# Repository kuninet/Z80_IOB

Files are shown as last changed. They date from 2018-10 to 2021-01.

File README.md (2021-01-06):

View this project on [CADLAB.io](https://cadlab.io/project/23712). 

# Z80 I/Oボード (KZ80-IOB)

詳細は[以下のwiki](https://github.com/kuninet/Z80_IOB/wiki)にまとめます。
ご覧ください。

https://github.com/kuninet/Z80_IOB/wiki

## 概要

- SBC8080ルーズキットバスにつながるI/Oボードです。
  - [Z80 CPUボード(KZ80-CPUB)](https://github.com/kuninet/Z80_CPUB/wiki)、[SBC8080](https://vintagechips.wordpress.com/2018/06/24/sbc8080-cpu%E3%83%AB%E3%83%BC%E3%82%BA%E3%82%AD%E3%83%83%E3%83%88/)、[SBC8085](https://vintagechips.wordpress.com/2018/08/27/sbc8085%e3%81%8c%e5%ae%8c%e6%88%90/)と組み合わせた稼働を確認しています。
  - 8255パラレルI/O LSIを搭載しています。(Lチカに最適)
  - 8251シリアルチップを搭載しています。
  - 将来 ArduinoコネクタのFM音源シールドを搭載するためのコネクタを装備しています。(これ以外の使いみちはありませんが...)

## 回路図

[回路図はこちら](image/Z80-8251-PPI.pdf)です。

## 部品表

[部品表はこちら](KiCAD/Z80-8251-PPI.ods)です。

※LibreOffice/OpenOfficeのcalcで開ける形式となっています。

## ライセンス

- 本リポジトリのデータは MIT License のもとで公開します。[LICENSE.txt](LICENSE.txt)を参照して下さい。

## その他注意点等

- 8251シリアルLSIのアドレスデコードをSBC8080 SUBボードと合わせる場合は、アドレスデコードジャンパ(J2)の1-2を短絡(I/Oアドレス:00h)してください。
- 8255パラレルI/O LSIのアドレスデコードジャンパ(J3)は 13-14を短絡(I/Oアドレス:C0h)が推奨です。

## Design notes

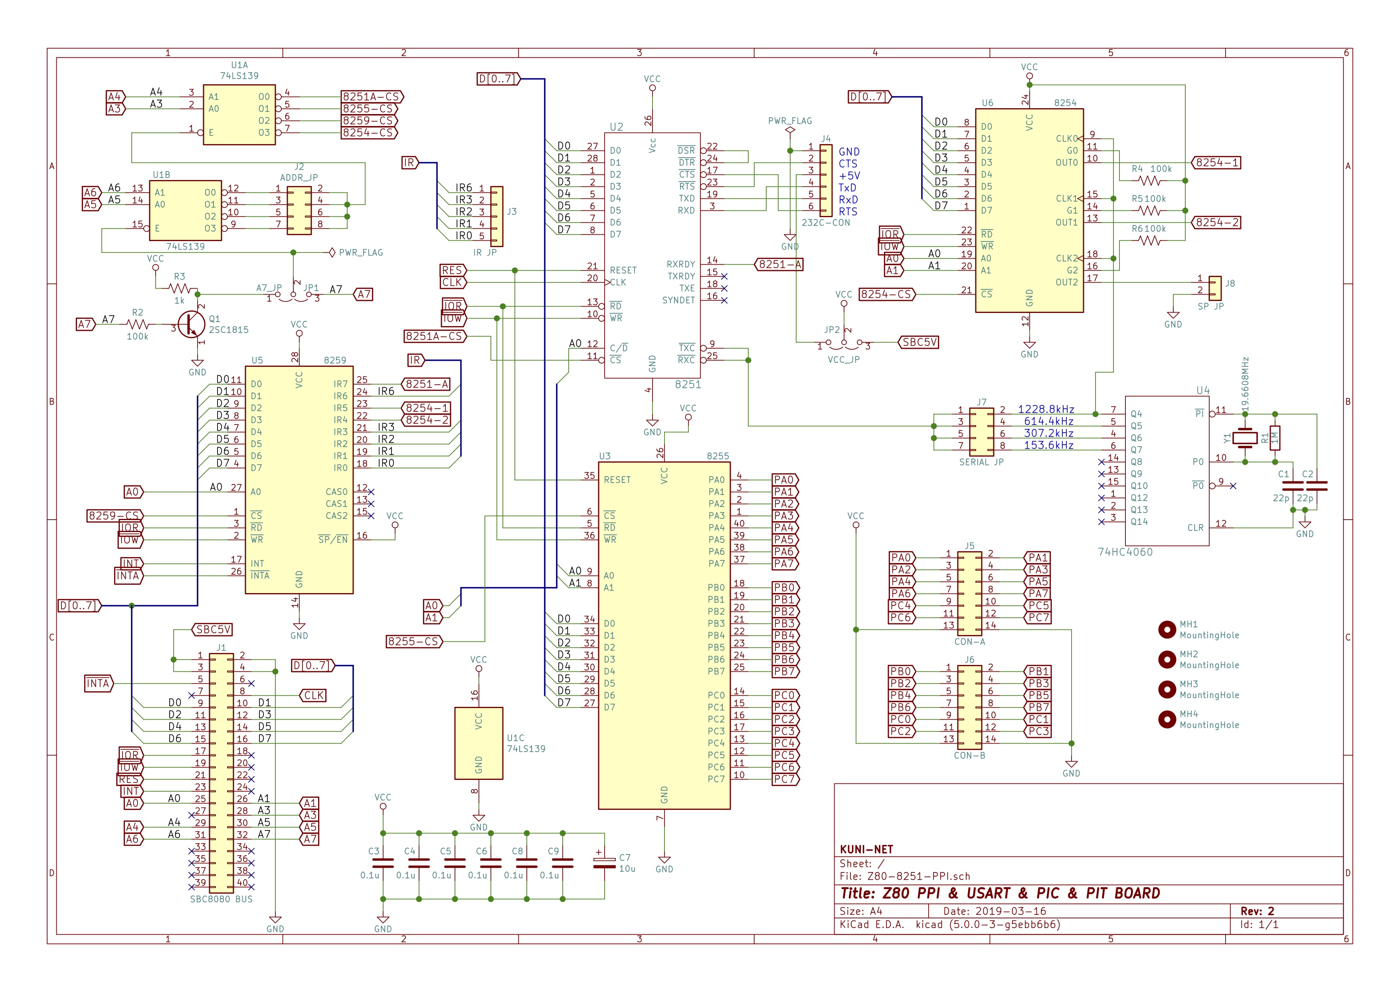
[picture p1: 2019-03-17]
image/Z80-8251-PPI.jpg

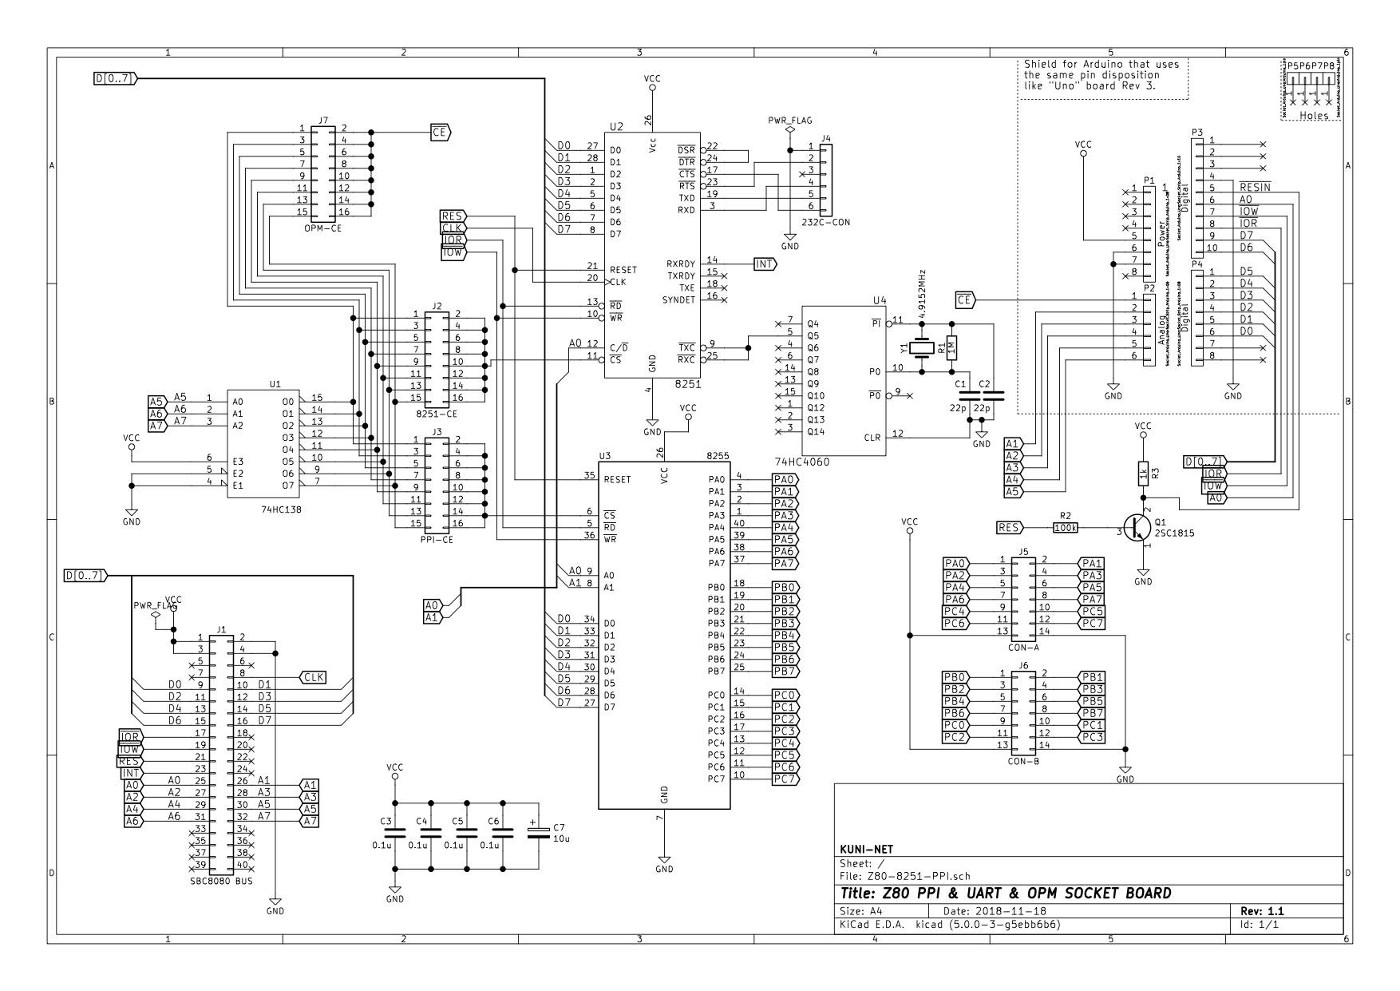
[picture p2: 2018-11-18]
image/Z80-8251-PPI-REV1.jpg

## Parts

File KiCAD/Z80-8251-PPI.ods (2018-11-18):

部品番号 | 仕様 | 数量 | 代替可能品 | 備考 | Footprint
P1 | ピンソケット 1列x8pin | 1 | - | ピンヘッダ1列x40pin等を切り分け | Socket_Arduino_Uno:Socket_Strip_Arduino_1x08
P2 | ピンソケット 1列x6pin | 1 | - | ピンヘッダ1列x40pin等を切り分け | Socket_Arduino_Uno:Socket_Strip_Arduino_1x06
P4 | ピンソケット 1列x8pin | 1 | - | ピンヘッダ1列x40pin等を切り分け | Socket_Arduino_Uno:Socket_Strip_Arduino_1x08
P3 | ピンソケット1列x10pin | 1 | - | ピンヘッダ1列x40pin等を切り分け | Socket_Arduino_Uno:Socket_Strip_Arduino_1x10
U1 | 74HC138 | 1 | 74HCT138 |  | Housings_DIP:DIP-16_W7.62mm_Socket
U2 | UPD8251AFC | 1 | Intel 8251 |  | Housings_DIP:DIP-28_W15.24mm_Socket
U3 | UPD8255AC-5 | 1 | M5L8255AP-5 |  | Housings_DIP:DIP-40_W15.24mm
U4 | 74HC4060 | 1 | 74HCT4060 |  | Housings_DIP:DIP-16_W7.62mm_Socket
J1 | 40 ピン L 型ボックスヘッダ | 1 | L型2列ピンヘッダ | L型2列ピンヘッダでも可 | Pin_Headers:Pin_Header_Angled_2x20
J2、J3、J7 | ピンヘッダ 2列x8pin | 3 | - | ピンヘッダ2列x40pin等を切り分け | Pin_Headers:Pin_Header_Straight_2x08
J4 | L型1列ピンヘッダ 6pin | 1 | - | L型ピンヘッダ1列x40pin等を切り分け | Pin_Headers:Pin_Header_Angled_1x06
J5、J6 | 14pin ボックスヘッダ | 2 | ピンヘッダ 2列x7pin | ピンヘッダで代替も可 | Pin_Headers:Pin_Header_Straight_2x07_Pitch2.54mm
Y1 | 4.9152MHz | 1 | 水晶振動子 |  | Crystals:HC-49V
R1 | 1MΩ | 1 | カーボン抵抗器 |  | Resistors_THT:R_Axial_DIN0207_L6.3mm_D2.5mm_P10.16mm_Horizontal
R2 | 100kΩ | 1 | カーボン抵抗器 |  | Resistors_THT:R_Axial_DIN0207_L6.3mm_D2.5mm_P10.16mm_Horizontal
R3 | 1kΩ | 1 | カーボン抵抗器 |  | Resistors_THT:R_Axial_DIN0207_L6.3mm_D2.5mm_P10.16mm_Horizontal
C1、C2 | 22pF | 2 | 積層セラミックコンデンサ |  | Capacitors_THT:C_Rect_L4.0mm_W2.5mm_P2.50mm
C3、C4、C5、C6 | 0.1μF | 4 | 積層セラミックコンデンサ |  | Capacitors_THT:C_Rect_L4.0mm_W2.5mm_P2.50mm
Q1 | 2SC1815 | 1 | 小電力トランジスタ | 1815同等品ならOK
C7 | 10μF | 1 | 電解/タンタルコンデンサ |  | Capacitor_THT:CP_Radial_D5.0mm_P2.50mm

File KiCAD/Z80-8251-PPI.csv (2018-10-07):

Reference | Value | Footprint | Datasheet
P1 | Power | Socket_Arduino_Uno:Socket_Strip_Arduino_1x08
P2 | Analog | Socket_Arduino_Uno:Socket_Strip_Arduino_1x06
P5 | CONN_01X01 | Socket_Arduino_Uno:Arduino_1pin
P6 | CONN_01X01 | Socket_Arduino_Uno:Arduino_1pin
P7 | CONN_01X01 | Socket_Arduino_Uno:Arduino_1pin
P8 | CONN_01X01 | Socket_Arduino_Uno:Arduino_1pin
P4 | Digital | Socket_Arduino_Uno:Socket_Strip_Arduino_1x08
P3 | Digital | Socket_Arduino_Uno:Socket_Strip_Arduino_1x10
U3 | 8255 | Housings_DIP:DIP-40_W15.24mm
U2 | 8251 | Housings_DIP:DIP-28_W15.24mm_Socket
J2 | 8251-CE | Pin_Headers:Pin_Header_Straight_2x08
J3 | PPI-CE | Pin_Headers:Pin_Header_Straight_2x08
U1 | 74HC138 | Housings_DIP:DIP-16_W7.62mm_Socket
J1 | SBC8080 BUS | Pin_Headers:Pin_Header_Angled_2x20
J5 | CON-A | Pin_Headers:Pin_Header_Straight_2x07_Pitch2.54mm
J6 | CON-B | Pin_Headers:Pin_Header_Straight_2x07_Pitch2.54mm
J4 | 232C-CON | Pin_Headers:Pin_Header_Angled_1x06
J7 | OPM-CE | Pin_Headers:Pin_Header_Straight_2x08
U4 | 74HC4060 | Housings_DIP:DIP-16_W7.62mm_Socket
Y1 | 4.9152MHz | Crystals:HC-49V
R1 | 1M | Resistors_THT:R_Axial_DIN0207_L6.3mm_D2.5mm_P10.16mm_Horizontal
C2 | 22p | Capacitors_THT:C_Rect_L4.0mm_W2.5mm_P2.50mm
C1 | 22p | Capacitors_THT:C_Rect_L4.0mm_W2.5mm_P2.50mm
C3 | 0.1u | Capacitors_THT:C_Rect_L4.0mm_W2.5mm_P2.50mm
C4 | 0.1u | Capacitors_THT:C_Rect_L4.0mm_W2.5mm_P2.50mm
C5 | 0.1u | Capacitors_THT:C_Rect_L4.0mm_W2.5mm_P2.50mm
C6 | 0.1u | Capacitors_THT:C_Rect_L4.0mm_W2.5mm_P2.50mm

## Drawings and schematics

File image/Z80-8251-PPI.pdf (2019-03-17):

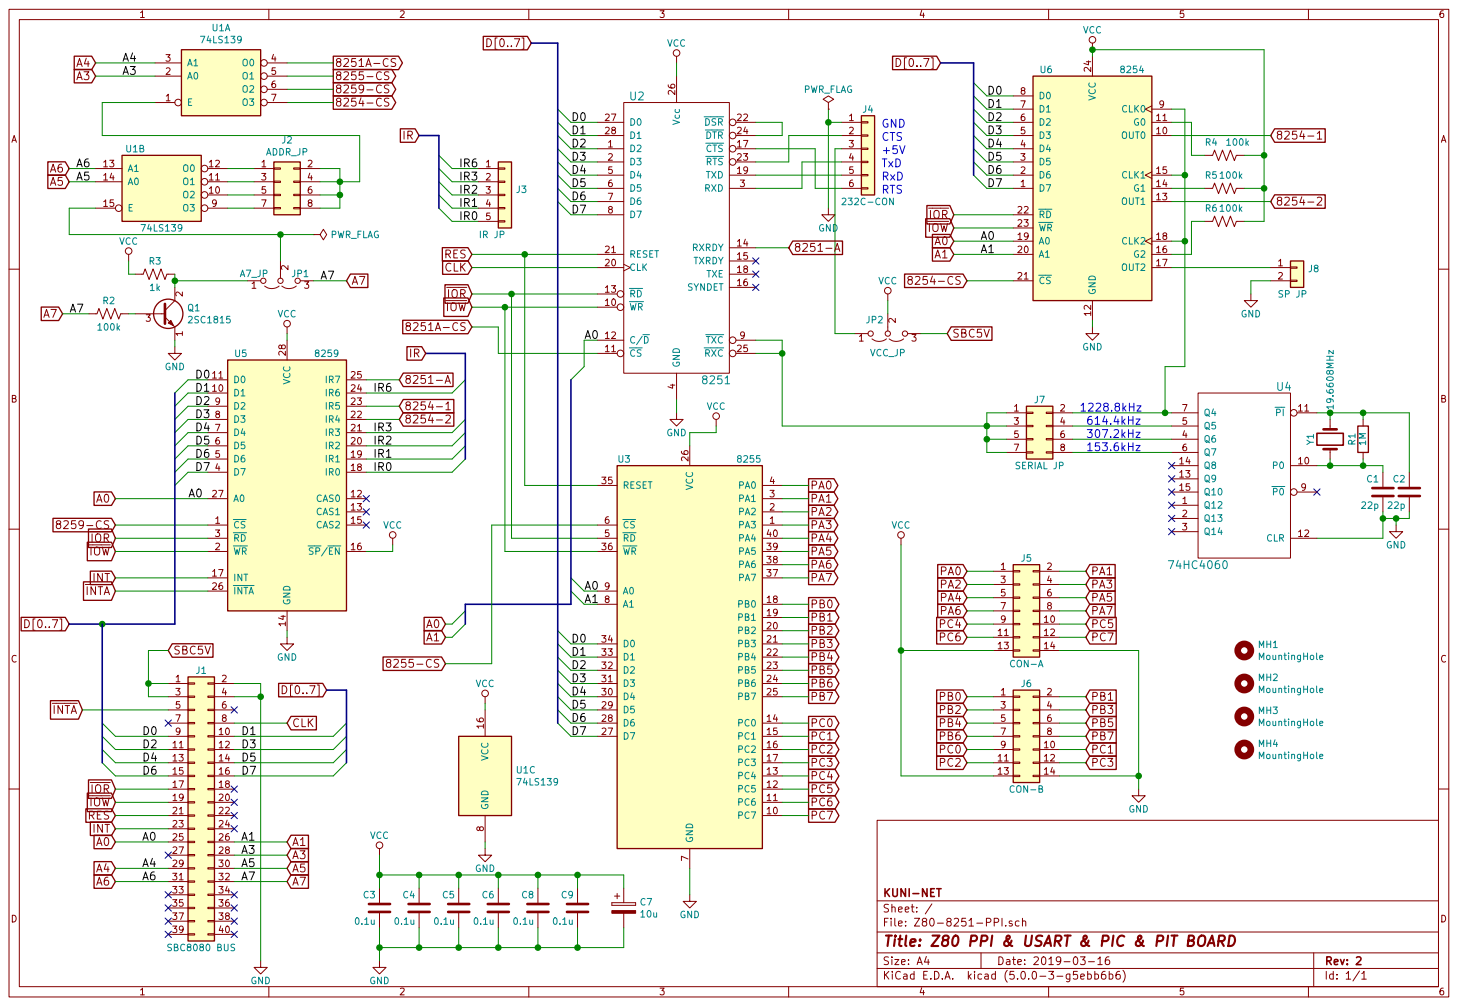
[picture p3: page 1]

7 A1 8 A0 9 U3 8255 D2 1 WR 10 CS 11 C/D 12 RD 13 RXRDY 14 TXRDY 15 SYNDET 16 CTS 17 TXE 18 TXD 19 D3 2 CLK 20 RESET 21 DSR 22 RTS 23 DTR 24 RXC 25 Vcc 26 D0 27 D1 28 RXD 3 GND

File: Z80-8251-PPI.sch Sheet: / KUNI-NET

Id: 1/1 Title: Z80 PPI & USART & PIC & PIT BOARD

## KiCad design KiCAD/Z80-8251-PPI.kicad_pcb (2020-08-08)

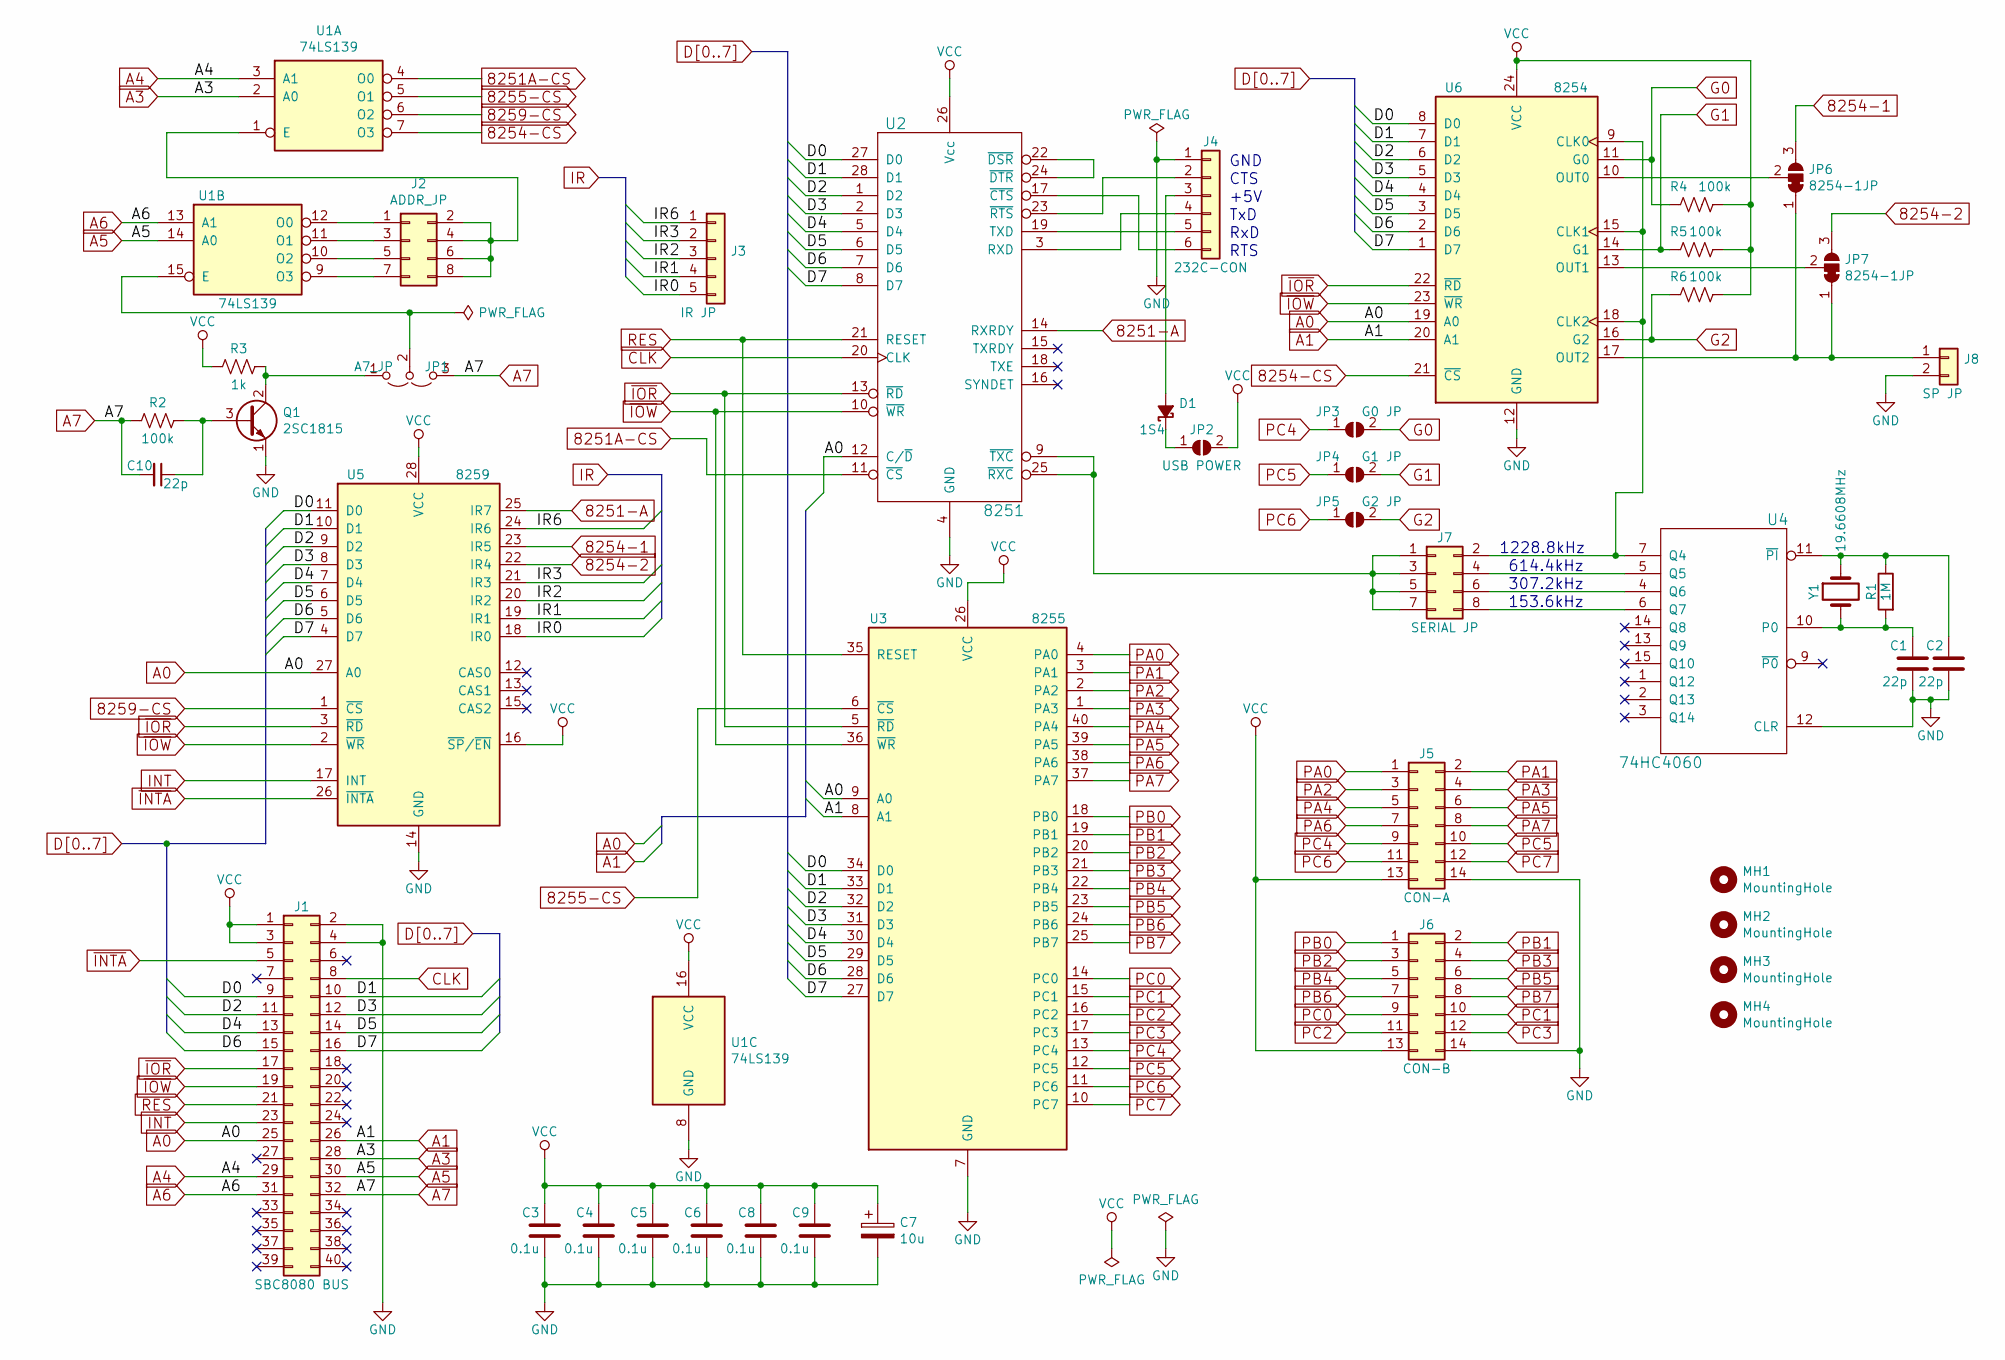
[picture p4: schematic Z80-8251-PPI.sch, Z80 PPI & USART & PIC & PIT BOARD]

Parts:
C1, C2, C10: 22p; C_Disc_D3.0mm_W1.6mm_P2.50mm
C3, C4, C5, C6, C8, C9: 0.1u; C_Disc_D3.0mm_W1.6mm_P2.50mm
C7: 10u; CP_Radial_D5.0mm_P2.50mm
D1: 1S4; D_DO-34_SOD68_P7.62mm_Horizontal
J1: SBC8080 BUS; Pin_Header_Angled_2x20
J2: ADDR_JP; PinHeader_2x04_P2.54mm_Vertical
J3: IR JP; PinHeader_1x05_P2.54mm_Horizontal
J4: 232C-CON; PinHeader_1x06_P2.54mm_Horizontal
J5: CON-A; PinHeader_2x07_P2.54mm_Vertical
J6: CON-B; PinHeader_2x07_P2.54mm_Vertical
J7: SERIAL JP; PinHeader_2x04_P2.54mm_Vertical
J8: SP JP; PinHeader_1x02_P2.54mm_Horizontal
JP1: A7_JP; PinHeader_1x03_P2.54mm_Vertical
JP2: USB POWER; SolderJumper-2_P1.3mm_Open_RoundedPad1.0x1.5mm
JP3: G0 JP; SolderJumper-2_P1.3mm_Open_RoundedPad1.0x1.5mm
JP4: G1 JP; SolderJumper-2_P1.3mm_Open_RoundedPad1.0x1.5mm
JP5: G2 JP; SolderJumper-2_P1.3mm_Open_RoundedPad1.0x1.5mm
JP6, JP7: 8254-1JP; SolderJumper-3_P1.3mm_Bridged12_RoundedPad1.0x1.5mm
MH1, MH2, MH3, MH4: MountingHole; MountingHole_3.2mm_M3
Q1: 2SC1815; TO-92_Inline_Wide
R1: 1M; R_Axial_DIN0207_L6.3mm_D2.5mm_P10.16mm_Horizontal
R2, R4, R5, R6: 100k; R_Axial_DIN0207_L6.3mm_D2.5mm_P10.16mm_Horizontal
R3: 1k; R_Axial_DIN0207_L6.3mm_D2.5mm_P10.16mm_Horizontal
U1: 74LS139; DIP-16_W7.62mm_Socket
U2: 8251; DIP-28_W15.24mm_Socket
U3: 8255; DIP-40_W15.24mm_Socket
U4: 74HC4060; DIP-16_W7.62mm_Socket
U5: 8259; DIP-28_W15.24mm_Socket
U6: 8254; DIP-24_W15.24mm_Socket
Y1: 19.6608MHz; HC-49V

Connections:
8251-A: U2.14 (RXRDY), U5.25 (IR7)
8251A-CS: U1.4 (O0), U2.11 (~CS)
8254-1: JP6.3 (B), U5.23 (IR5)
8254-2: JP7.3 (B), U5.22 (IR4)
8254-CS: U1.7 (O3), U6.21 (~CS~)
8255-CS: U1.5 (O1), U3.6 (~CS~)
8259-CS: U1.6 (O2), U5.1 (~CS~)
/IR0: J3.5, U5.18 (IR0)
/IR1: J3.4, U5.19 (IR1)
/IR2: J3.3, U5.20 (IR2)
/IR3: J3.2, U5.21 (IR3)
/IR6: J3.1, U5.24 (IR6)
A0: J1.25, U2.12 (C/~D), U3.9 (A0), U5.27 (A0), U6.19 (A0)
A1: J1.26, U3.8 (A1), U6.20 (A1)
A3: J1.28, U1.2 (A0)
A4: J1.29, U1.3 (A1)
A5: J1.30, U1.14 (A0)
A6: J1.31, U1.13 (A1)
A7: C10.2, J1.32, JP1.3 (B), R2.2
CLK: J1.8, U2.20 (CLK)
D0: J1.9, U2.27 (D0), U3.34 (D0), U5.11 (D0), U6.8 (D0)
D1: J1.10, U2.28 (D1), U3.33 (D1), U5.10 (D1), U6.7 (D1)
D2: J1.11, U2.1 (D2), U3.32 (D2), U5.9 (D2), U6.6 (D2)
D3: J1.12, U2.2 (D3), U3.31 (D3), U5.8 (D3), U6.5 (D3)
D4: J1.13, U2.5 (D4), U3.30 (D4), U5.7 (D4), U6.4 (D4)
D5: J1.14, U2.6 (D5), U3.29 (D5), U5.6 (D5), U6.3 (D5)
D6: J1.15, U2.7 (D6), U3.28 (D6), U5.5 (D6), U6.2 (D6)
D7: J1.16, U2.8 (D7), U3.27 (D7), U5.4 (D7), U6.1 (D7)
G0: JP3.2 (B), R4.2, U6.11 (G0)
G1: JP4.2 (B), R5.2, U6.14 (G1)
G2: JP5.2 (B), R6.2, U6.16 (G2)
GND: C1.2, C2.2, C3.2, C4.2, C5.2, C6.2, C7.2, C8.2, C9.2, J1.2, J1.4, J4.1, J5.14, J6.14, J8.2, Q1.1 (E), U1.8 (GND), U2.4 (GND), U3.7 (GND), U4.8 (GND), U4.12 (CLR), U5.14 (GND), U6.12 (GND)
INT: J1.23, U5.17 (INT)
unnamed: C1.1, R1.2, U4.10 (P0), Y1.2
unnamed: C2.1, R1.1, U4.11 (~PI), Y1.1
unnamed: C10.1, Q1.3 (B), R2.1
unnamed: D1.1 (K), JP2.1 (A)
unnamed: D1.2 (A), J4.3
unnamed: J2.1, U1.12 (O0)
unnamed: J2.2, J2.4, J2.6, J2.8, U1.1 (E)
unnamed: J2.3, U1.11 (O1)
unnamed: J2.5, U1.10 (O2)
unnamed: J2.7, U1.9 (O3)
unnamed: J4.2, U2.23 (~RTS)
unnamed: J4.4, U2.3 (RXD)
unnamed: J4.5, U2.19 (TXD)
unnamed: J4.6, U2.17 (~CTS)
unnamed: J7.1, J7.3, J7.5, J7.7, U2.9 (~TXC), U2.25 (~RXC)
unnamed: J7.2, U4.7 (Q4), U6.9 (CLK0), U6.15 (CLK1), U6.18 (CLK2)
unnamed: J7.4, U4.5 (Q5)
unnamed: J7.6, U4.4 (Q6)
unnamed: J7.8, U4.6 (Q7)
unnamed: J8.1, JP6.1 (A), JP7.1 (A), U6.17 (OUT2)
unnamed: JP1.1 (A), Q1.2 (C), R3.1
unnamed: JP1.2 (C), U1.15 (E)
unnamed: JP6.2 (C), U6.10 (OUT0)
unnamed: JP7.2 (C), U6.13 (OUT1)
unnamed: U2.22 (~DSR), U2.24 (~DTR)
PA0: J5.1, U3.4 (PA0)
PA1: J5.2, U3.3 (PA1)
PA2: J5.3, U3.2 (PA2)
PA3: J5.4, U3.1 (PA3)
PA4: J5.5, U3.40 (PA4)
PA5: J5.6, U3.39 (PA5)
PA6: J5.7, U3.38 (PA6)
PA7: J5.8, U3.37 (PA7)
PB0: J6.1, U3.18 (PB0)
PB1: J6.2, U3.19 (PB1)
PB2: J6.3, U3.20 (PB2)
PB3: J6.4, U3.21 (PB3)
PB4: J6.5, U3.22 (PB4)
PB5: J6.6, U3.23 (PB5)
PB6: J6.7, U3.24 (PB6)
PB7: J6.8, U3.25 (PB7)
PC0: J6.9, U3.14 (PC0)
PC1: J6.10, U3.15 (PC1)
PC2: J6.11, U3.16 (PC2)
PC3: J6.12, U3.17 (PC3)
PC4: J5.9, JP3.1 (A), U3.13 (PC4)
PC5: J5.10, JP4.1 (A), U3.12 (PC5)
PC6: J5.11, JP5.1 (A), U3.11 (PC6)
PC7: J5.12, U3.10 (PC7)
RES: J1.21, U2.21 (RESET), U3.35 (RESET)
VCC: C3.1, C4.1, C5.1, C6.1, C7.1, C8.1, C9.1, J1.1, J1.3, J5.13, J6.13, JP2.2 (B), R3.2, R4.1, R5.1, R6.1, U1.16 (VCC), U2.26 (Vcc), U3.26 (VCC), U4.16 (VCC), U5.16 (~SP~/~EN~), U5.28 (VCC), U6.24 (VCC)
~INTA: J1.5, U5.26 (~INTA~)
~IOR: J1.17, U2.13 (~RD), U3.5 (~RD~), U5.3 (~RD~), U6.22 (~RD~)
~IOW: J1.19, U2.10 (~WR), U3.36 (~WR~), U5.2 (~WR~), U6.23 (~WR~)

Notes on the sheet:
1228.8kHz
614.4kHz
307.2kHz
153.6kHz
GND
CTS
+5V
TxD
RxD
RTS

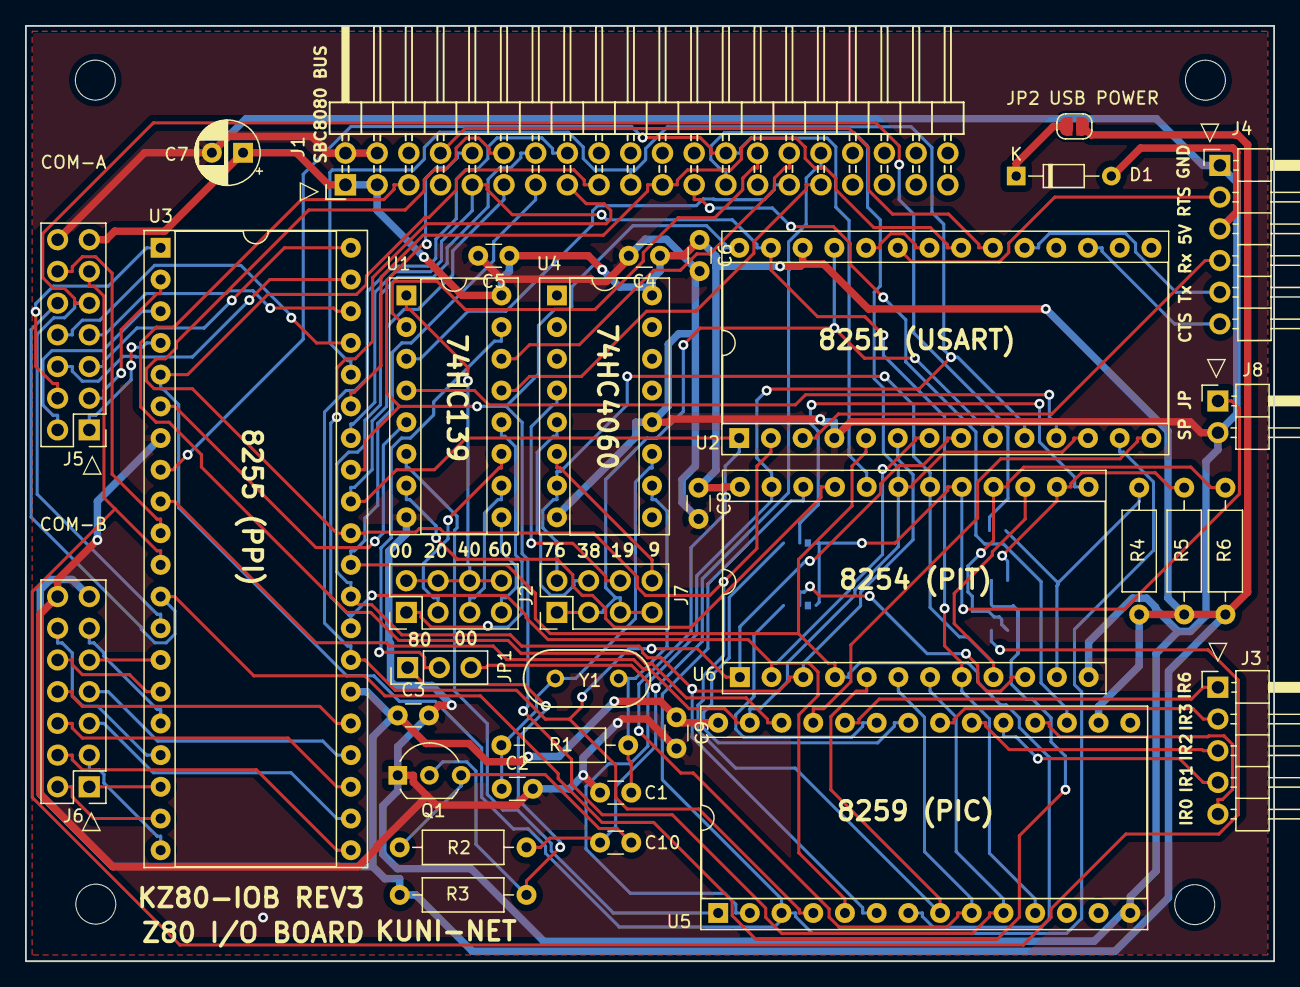
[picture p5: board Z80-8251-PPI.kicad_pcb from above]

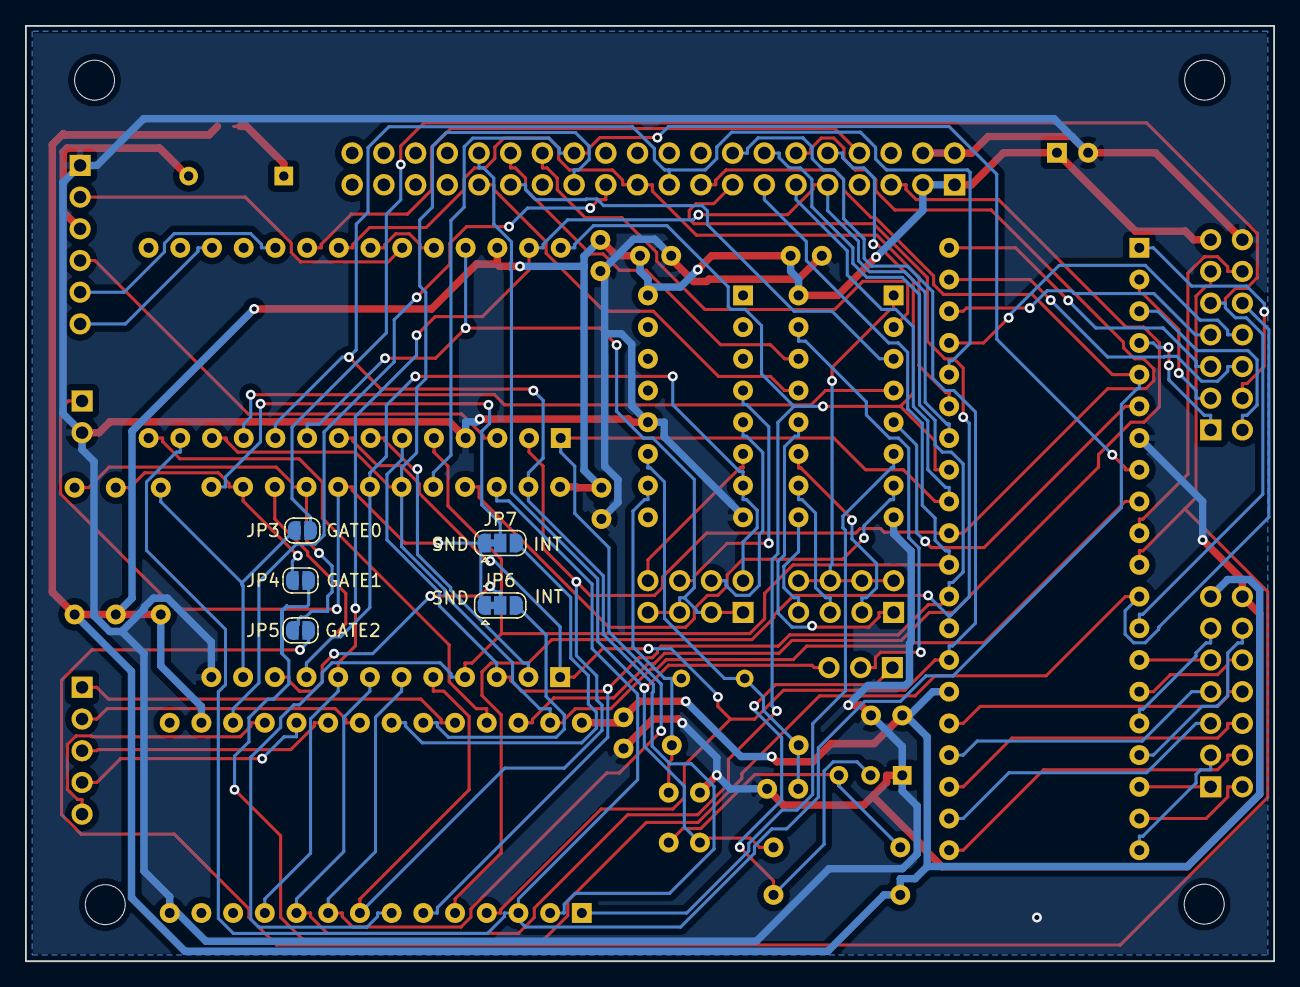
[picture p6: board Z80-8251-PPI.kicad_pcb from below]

Board: 2 copper layers, 100.0 x 74.9 mm, 44 parts (5 on the bottom side), 87 nets.

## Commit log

2018-10-07 KiCADデータ等整備
    [Z80-8251-PPI-2018-09-24-20-06-07.sch, Z80-8251-PPI-2018-10-01-22-44-03.sch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]
2018-10-22 PPIコネクタ再配置、電解コンデンサ追加、シルク見直し
    [Z80-8251-PPI.dsn, Z80-8251-PPI.kicad_pcb, Z80-8251-PPI.sch]
2018-11-18 Rev1.1パターン見直し
    [Z80-8251-PPI.kicad_pcb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]
2018-11-18 REV1.1回路図更新
    [Z80-8251-PPI.sch]
2018-11-18 部品表修正
    [Z80-8251-PPI.ods]
2019-03-17 REV2 回路図、製造データ出力
    [Z80-8251-PPI.dsn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]
2019-03-17 旧回路図(REV1) 別ファイルへ
2020-08-08 REV3 回路図、パターン検討 その1
    [Z80-8251-PPI.dsn, Z80-8251-PPI.kicad_pcb, Z80-8251-PPI.sch]
2020-08-08 FTDI +5Vへダイオード追加
    [Z80-8251-PPI.kicad_pcb, Z80-8251-PPI.sch]
2022-05-04 LED ブリンクサンプル追加
